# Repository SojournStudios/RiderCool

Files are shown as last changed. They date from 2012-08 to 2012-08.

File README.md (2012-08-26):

========
Overview and Description
========

>> RiderCool by Kristopher Kortright, June 2012 - Aug 2012 (o_o)
*>  This software is licensed via CERN Open Source Hardware License.
->  Must of this script was derived from tutorial code by Limor Fried 
->  and Adafruit Industries, and most of the credit goes to her and 
->  her company for providing such fantastic tutorials to the community!
->  Adafruit tutorials used can be found at http://learn.adafruit.com
->  My blog and projects can be found at http://sojournstudio.org/RiderCool

RiderCool has many purposes: 

1. Provide a technology platform for managing the pool with native XBee Network Protocol (XNP) support for sending data back for logging and to receive commands from a control router. 
2. To measure how full our pool is, and report that data back to my computer using my XBee Network Protocol (XNP) for logging and tracking (http://sojournstudio.org/xnp/)
3. To activate a solenoid/valve that is connected to a garden hose, which will fill the pool with water. 
4. To monitor, track and report-back the flow-rate of water going into the pool using an Adafruit flow-meter sensor (https://www.adafruit.com/products/828).
5. To monitor the temperature of the pool water, the ambient air, as well as ther CPU temp (https://www.adafruit.com/products/339), (https://www.adafruit.com/products/372)
6. To monitor a backup water-level sensor to ensure that the pool never over-flows.
7. To drive/control 4 RGB LED Strip controllers by Jeremy Saglimbeni; I have 40 meters of LED RGB Strip ringing-the pool. (http://thecustomgeek.com/2012/03/23/rgb ... r-ver-2-2/)
8. To displays the output of these sensors, LED status, etc on an Adafruit 1.8' TFT display for swimmers in the pool to see. (https://www.adafruit.com/products/358)
9. To provide button control resetting the system and controlling the RGB LED Strips using LED water-proof lights by Adafruit. (https://www.adafruit.com/products/482)
10. To teach me 3D printing - as this is my first 3D printing project with my MakerBot Replicator! (http://store.makerbot.com/replicator.html).
.
RiderCool was only possible because of the excellent products, tutorials and service that Limor Fried and her company Adafruit Industries provides to its customers, and I have become a dedicated fan over the 1.5 years I've been making. With this project I got to learn 3D printing and got some real use out of my years in Blender training. I also got to combine different products in a completely water-proof system. Now that it's done, of course, the summer is over and its nearly time to close the pool down. But building this helped me through alot of dark days this summer.
.
There are 4 modules (Otter Boxes) in the RiderCool system, each of which is documented below. I can only add 3 images to a post, so I'll reply to the post and add more content/images so I can show the creation pics as well as the final product when shown in action (Coming Soon!). The Power Module is a small-sized otter box with a laptop 12v/5A power supply and an adafruit 5V 2A power supply (https://www.adafruit.com/products/276) with the grounds tied-together.

The green power-button is actually not a power-button for the entire system, but rather a bypass power option that allows me to run the RGB LED Controllers by themselves without the Arduino Mega system controlling them (http://www.adafruit.com/products/916). 
.
The Interface Module combines an Adafruit 1.8' TFT display (http://www.adafruit.com/products/358) and several more water-proof buttons to allow users the ability to view the sensor stats and control the RGB LED strips while swimming in the pool.

Each of the 4 modules (otter boxes) are connected together using the new Adafruit waterproof power connectors (http://www.adafruit.com/products/743) and their new waterproof 4-wire connectors (http://www.adafruit.com/products/744). I love these things, and they came in very handy when the project grew beyond the size of one otter box! I plan to use them on most of my projects.

Lastly the RGB LED Controller module combines 4 of Jeremy's RGB LED controllers (http://thecustomgeek.com/2012/03/23/rgb ... r-ver-2-2/) in one large otter box, with the serial ports tied-together and fed into the Arduino for control. The switch allows me to use the strips manually (when combined with the green power button on the Power Module).

=========
Installation
=========
Simply install the RiderCoolNonXNP.pde script in your favorite arduino sketch directory, and load it as a project.
 
The sketch will compile cleanly on Arduino IDE v1.0.1 using the Arduino Mega 2560 as the board type.
 
You can follow-along with any changes I make here on GitHub, and make sure to check the Adafruit Forum post for RiderCool (http://forums.adafruit.com/viewtopic.php?f=25&t=32488) as that's where I will post lots of detail about the updates and answer any questions.
 
Cheers!
 
Kris Kortright

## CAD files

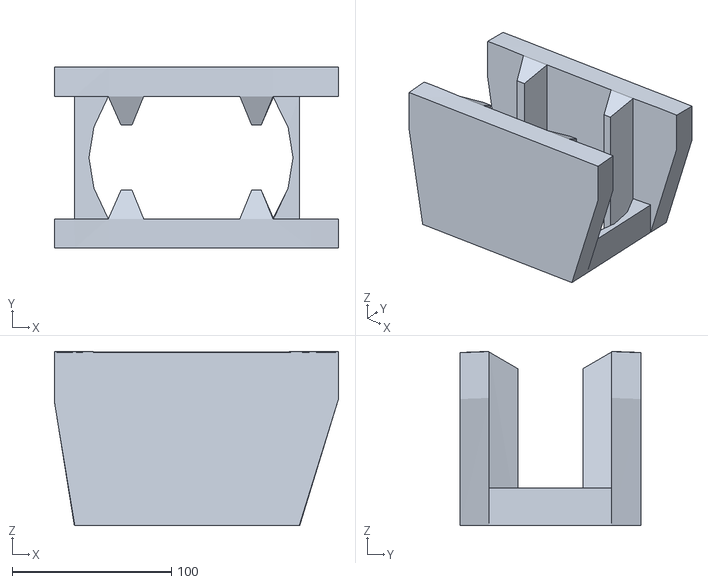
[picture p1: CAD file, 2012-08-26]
replicator/RiderCoolBacKMid4.stl
178.5 x 113.6 x 109.5

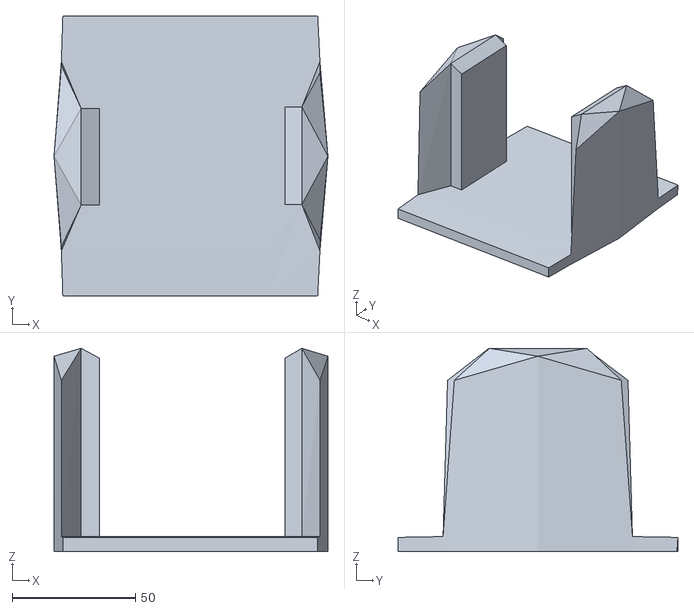
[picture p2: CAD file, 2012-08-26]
replicator/RiderCoolBackTop1.stl
111.2 x 113.6 x 82.5

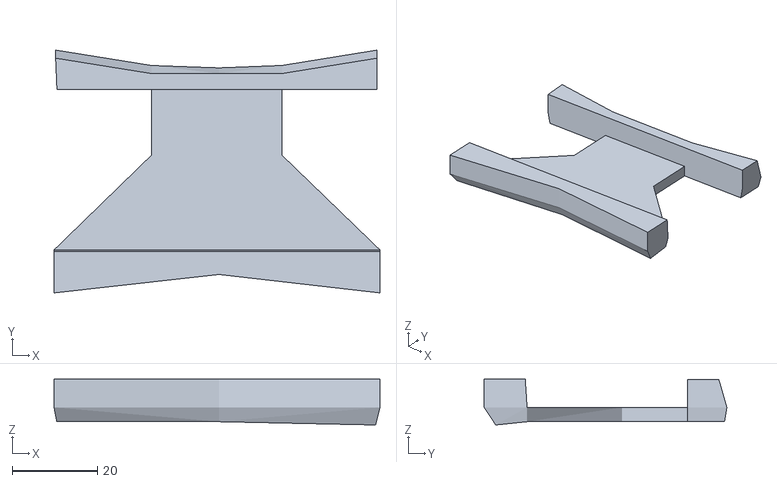
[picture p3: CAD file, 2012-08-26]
replicator/RiderCoolBackConnector1.stl
76.5 x 57.0 x 10.8

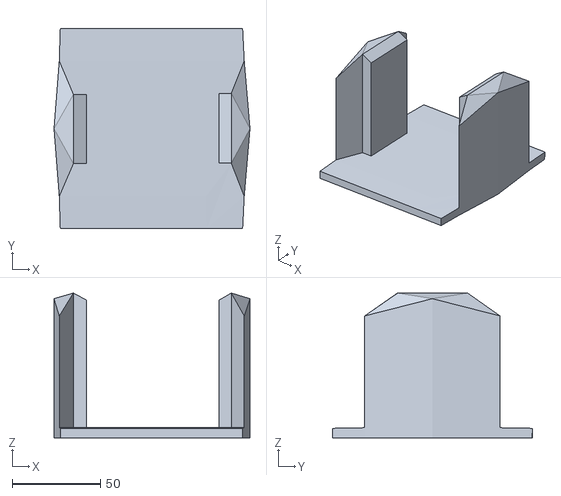
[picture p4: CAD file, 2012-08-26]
replicator/RiderCoolRearBaseTop1.stl
111.2 x 113.6 x 82.2

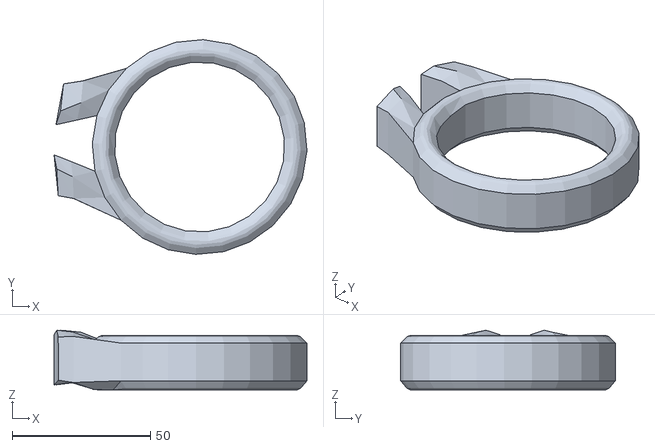
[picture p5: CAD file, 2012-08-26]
replicator/RiderCoolPoolRingMount.stl
91.6 x 77.7 x 21.6

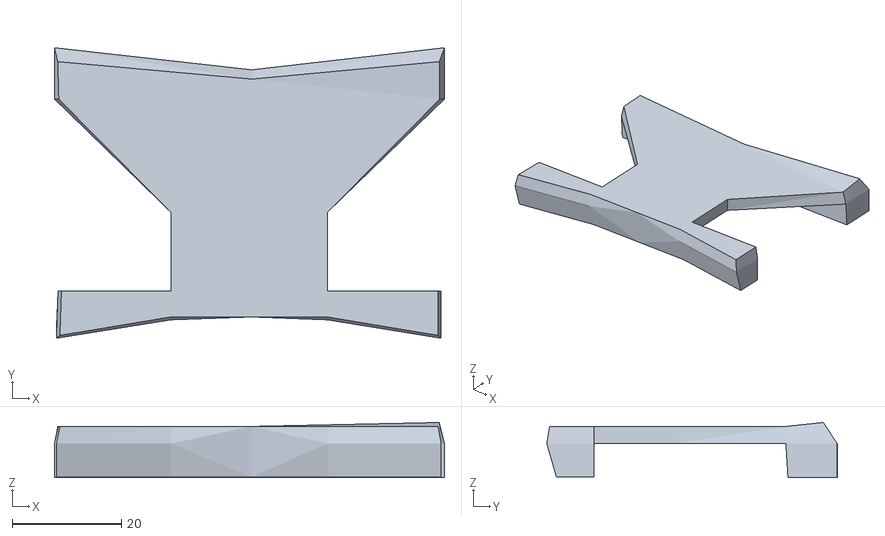
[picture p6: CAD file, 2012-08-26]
replicator/RiderCoolBaseLock1.stl
71.5 x 53.2 x 10.1

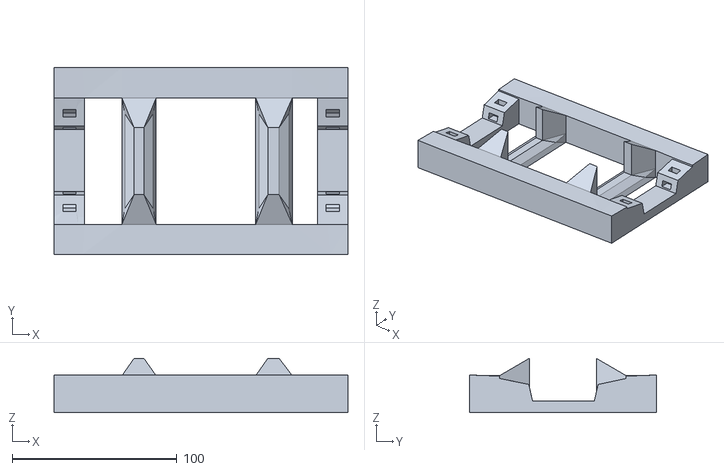
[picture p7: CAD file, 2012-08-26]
replicator/RiderCoolBackBase4.stl
178.5 x 113.6 x 33.0

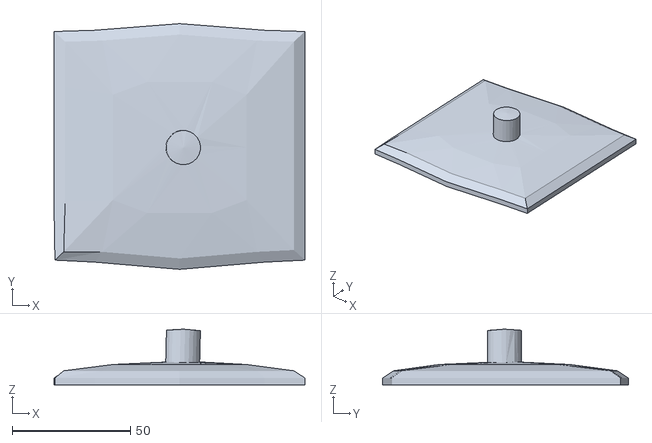
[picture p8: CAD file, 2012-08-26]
replicator/RiderCoolBackTopLid1.stl
106.1 x 103.9 x 23.6

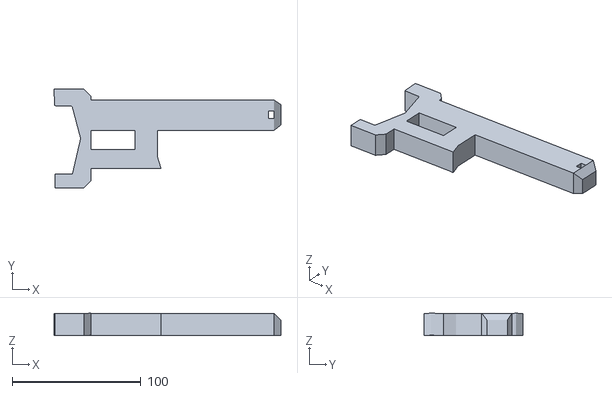
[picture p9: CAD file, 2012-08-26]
replicator/RiderCoolVertialRack4.stl
176.1 x 76.9 x 17.5

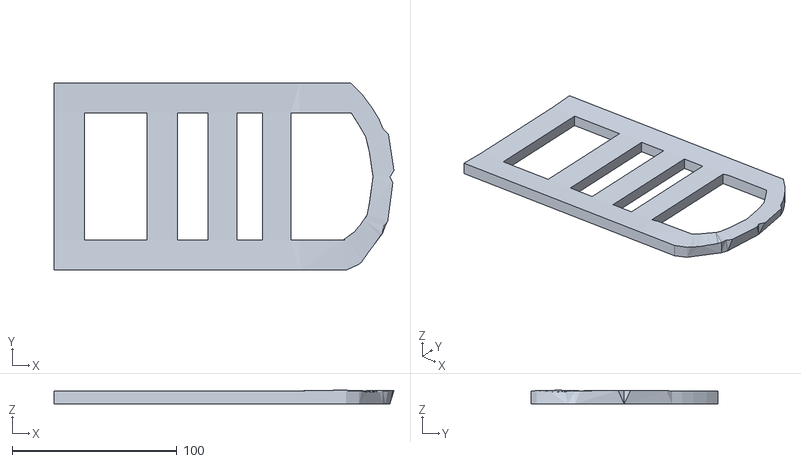
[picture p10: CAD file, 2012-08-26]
replicator/RiderCoolFrontBaseLowerWedge1.stl
206.1 x 113.6 x 8.39

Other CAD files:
blender/RiderCoolV1.blend

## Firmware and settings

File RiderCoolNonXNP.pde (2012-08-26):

/* =-=-=-=-=-=-=-=-=-=-=-=-=-=-=-=-=-=-=-=-=-=-=-=-=-=-=-=-=-=-=-=-=-=-=-=
RiderCool by Kristopher Kortright, June 2012 - Aug 2012 (o_o)
This software is licensed via CERN Open Source Hardware License
=-=-=-=-=-=-=-=-=-=-=-=-=-=-=-=-=-=-=-=-=-=-=-=-=-=-=-=-=-=-=-=-=-=-=-=-=*/
#define VERSION            "Ver 1.0"

#include <Wire.h>
#include <SPI.h>  // not used here, but needed to prevent a RTClib compile error
#include "RTClib.h"
RTC_Millis RTC;

#include <Adafruit_GFX.h>
#include <Adafruit_ST7735.h>
#include <SPI.h>
#include <Adafruit_BMP085.h>
Adafruit_BMP085 bmp;

int DigitalPSTdrivePIN1 = 36;
int DigitalPSTdrivePIN2 = 37; 
int DigitalPSTdrivePIN3 = 38;
int DigitalPSTdrivePIN4 = 39; 
int DigitalRELAYdrivePIN = 46;
int DigitalPINnetworkStateLEDred = 25;
int DigitalPINnetworkStateLEDblue = 27;
int DigitalPINnetworkStateLEDgreen = 29;
int DigitalPINcontrollerPower = 47;
int DigitalPINRGBLEDstatus = 49;
int DigitalPINxbeePacketInLED = 45;       
int DigitalPINxbeePacketOutLED = 44;
int DigitalPINxbeepacketLossLED = 43;
int AnalogPINrotaryA0 = 54;
int AnalogPINrotaryA1 = 55;
int AnalogPINrotaryA2 = 56;
int AnalogPINrotaryA3 = 57;
int AnalogPINtmp36tempA7 = 61;
int AnalogPINphotoCellA8 = 62;
int AnalogPINphotoCellA9 = 63;
int AnalogThermistorSensorPIN1 = 67;
int AnalogThermistorSensorPIN2 = 65;
int AnalogThermistorSensorPIN3 = 66;
int AnalogPINliquidLevelSensorA13 = 64;
int AnalogPINliquidLevelSensorA15 = 69;
int FlowSensorPIN = 58;
int AnalogPINbutton1 = 59;
int AnalogPINbutton2 = 60;
int TFT18shieldSCLKpin = 52;
int TFT18shieldMOSIpin = 51;
int DigitalTFT18shieldCsPIN = 53;
int DigitalTFT18shieldDcPIN = 9;
int DigitalTFT18shieldRstPIN = 8;
int DigitalTFT18shieldLightPIN  = 50;

#define MAX_BUFFER_LENGTH 192
int MAX_BUFFER_LENGTHS = 192;

int POWERSWITCH_ENABLE = 1;
int ButtonOneState = 1;
int ButtonTwoState = 1;
long e, f, g;
int a, b, c, d, h, j, k, r, s, t, x, y, z;
char buffer1[MAX_BUFFER_LENGTH], buffer2[MAX_BUFFER_LENGTH], buffer3[MAX_BUFFER_LENGTH], inChar;
int TempSensorCount = 3;
int MinutesNow, MinutesWas, HoursNow, SegmentCounter;
int MasterTEMPstatus = -1;
int AIRtempHIcount, CPUtempHIcount, COOLANTtempHIcount;
int TemperatureAIR, TemperatureCPU, TemperatureCOOLANT;
int TempHIwarnLevelAIR, TempHIalarmLevelAIR;
int TempHIwarnLevelCPU, TempHIalarmLevelCPU;
int TempHIwarnLevelCOOLANT, TempHIalarmLevelCOOLANT;
int AIRtempHIcountMAX, CPUtempHIcountMAX, COOLANTtempHIcountMAX;
float SensorAverageReading;
float steinhart;
float temperatureF;
int ThermistorTemp;
int SensorSamples[5];
int SensorSettleDelay;
long MasterSensor;
int FlexBaseline;
int LightLevel, FlexResistance, Tmp36temp;
int MAXIMUM_POOL_LEVEL = 200;
int MINIMUM_POOL_LEVEL = 240;
int FluidLevelAlarming = 0;
int poolButtonOneDelay = 0;
int poolButtonTwoDelay = 20;
int poolButtonOneCount, poolButtonTwoCount, WaterHoseValve;
int MiloneSensorReading, FloatSensorReading, FluidSensorReading, UnderFillAlarms;
int BMP085TempReading, BMP085PressureReading, BMP085AltitueReading;
int lastflowpinstate, FlowSensorReading, lastFlowSensorReadingtimer, pulses, flowpinstate;
int SensorModuleActive, SensorSamplePass, LightLevel2, PoolWaterLevelNum, PoolWaterLevelDem;
int BMPtemperatureRemain, BMPaltitudeRemain, varInBuf1, Remain1;
int BMPtemperature, BMPaltitude, SensorDisplayScreen, BMPsensorVectorNow;
int BMPpressureLastReading, BMPsensorCount, BMPsensorUpReadings, BMPsensorDownReadings, BMPpressureLastHour;
float fRemain1, fStart;
uint32_t BMPpressure, checkTime;

Adafruit_ST7735 tft = Adafruit_ST7735(DigitalTFT18shieldCsPIN, DigitalTFT18shieldDcPIN, DigitalTFT18shieldRstPIN);


// Sensor Constants - These were taken from example code by LadyAda (http://www.ladyada.net/learn/sensors/thermistor.html)
//  TMP36 Constants: (Touch these ONLY if you know what your doing, and even then I would be careful).
//  Tie the 3.3V bus to ARef so that the sensors are more accurate.
#define aref_voltage 3.3         
// Thermistor:
//   resistance at 25 degrees C
#define THERMISTORNOMINAL 10000      
//   temp. for nominal resistance (almost always 25 C)
#define TEMPERATURENOMINAL 25   
//   how many samples to take and SensorAverageReading, more takes longer
//   but is more 'smooth'
#define NUMSAMPLES 5
//   The beta coefficient of the thermistor (usually 3000-4000)
#define BCOEFFICIENT 3950
//   the value of the 'other' resistor
#define SERIESRESISTOR 10000    



void XNPlogger(const char *buffer4, int linefeed)
{
  if((linefeed == 0) || (linefeed == 1)) {   // If we want time-stamps on our log messages
    DateTime now = RTC.now();
    checkTime = now.unixtime();
    Serial.print("[");
    Serial.print(checkTime);
    Serial.print("] ");
  }
  if((linefeed == 1) || (linefeed == 3)) {
    Serial.print(buffer4);
  } else if((linefeed == 0) || (linefeed == 2)) {
    Serial.println(buffer4);
  }
}


void XNPcollectSensorData()
{
  if(SensorModuleActive == 1) {
    SensorSamplePass++;
    if(SensorSamplePass == 1) {
      SensorSamples[0] = analogRead(AnalogThermistorSensorPIN1);
    } else if(SensorSamplePass == 21) {
      SensorSamples[1] = analogRead(AnalogThermistorSensorPIN1);
    } else if(SensorSamplePass == 41) {
      SensorSamples[2] = analogRead(AnalogThermistorSensorPIN1);
    } else if(SensorSamplePass == 61) {
      SensorSamples[3] = analogRead(AnalogThermistorSensorPIN1);
    } else if(SensorSamplePass == 81) {
      SensorSamples[4] = analogRead(AnalogThermistorSensorPIN1);
      SensorAverageReading = 0;
      for(b = 0; b < 5; b++) {
         SensorAverageReading += SensorSamples[b];
      }
      SensorAverageReading /= 5;
      SensorAverageReading = 1023 / SensorAverageReading - 1;
      SensorAverageReading = SERIESRESISTOR / SensorAverageReading;
      steinhart = 0;
      steinhart = SensorAverageReading / THERMISTORNOMINAL;
      steinhart = log(steinhart);
      steinhart /= BCOEFFICIENT;
      steinhart += 1.0 / (TEMPERATURENOMINAL + 273.15);
      steinhart = 1.0 / steinhart;
      steinhart -= 273.15;   
      temperatureF = (steinhart * 9.0 / 5.0) + 32.0;
      TemperatureAIR = int(temperatureF);
      sprintf(buffer2, " ");
      XNPlogger(buffer2, 2);
      sprintf(buffer2, "-] Sensor Readings:");
      XNPlogger(buffer2, 2);
      sprintf(buffer2, "-] Thermistor #1 Temperature Reading: %d F, AlarmCount: %d", TemperatureAIR, AIRtempHIcount); 
      XNPlogger(buffer2, 2);  
    } else if(SensorSamplePass == 101) {
      SensorSamples[0] = analogRead(AnalogThermistorSensorPIN2);
    } else if(SensorSamplePass == 121) {
      SensorSamples[1] = analogRead(AnalogThermistorSensorPIN2);
    } else if(SensorSamplePass == 141) {
      SensorSamples[2] = analogRead(AnalogThermistorSensorPIN2);
    } else if(SensorSamplePass == 161) {
      SensorSamples[3] = analogRead(AnalogThermistorSensorPIN2);
    } else if(SensorSamplePass == 181) {
      SensorSamples[4] = analogRead(AnalogThermistorSensorPIN2);
      SensorAverageReading = 0;
      for(b = 0; b < 5; b++) {
         SensorAverageReading += SensorSamples[b];
      }
      SensorAverageReading /= 5;
      SensorAverageReading = 1023 / SensorAverageReading - 1;
      SensorAverageReading = SERIESRESISTOR / SensorAverageReading;
      steinhart = 0;
      steinhart = SensorAverageReading / THERMISTORNOMINAL;
      steinhart = log(steinhart);
      steinhart /= BCOEFFICIENT;
      steinhart += 1.0 / (TEMPERATURENOMINAL + 273.15);
      steinhart = 1.0 / steinhart;
      steinhart -= 273.15;   
      temperatureF = (steinhart * 9.0 / 5.0) + 32.0;
      TemperatureCPU = int(temperatureF);
      sprintf(buffer2, "-] Thermistor #2 Temperature Reading: %d F, AlarmCount: %d", TemperatureCPU, CPUtempHIcount); 
      XNPlogger(buffer2, 2);  
    } else if(SensorSamplePass == 201) {
      SensorSamples[0] = analogRead(AnalogThermistorSensorPIN3);
    } else if(SensorSamplePass == 221) {
      SensorSamples[1] = analogRead(AnalogThermistorSensorPIN3);
    } else if(SensorSamplePass == 241) {
      SensorSamples[2] = analogRead(AnalogThermistorSensorPIN3);
    } else if(SensorSamplePass == 261) {
      SensorSamples[3] = analogRead(AnalogThermistorSensorPIN3);
    } else if(SensorSamplePass == 281) {
      SensorSamples[4] = analogRead(AnalogThermistorSensorPIN3);
      SensorAverageReading = 0;
      for(b = 0; b < 5; b++) {
         SensorAverageReading += SensorSamples[b];
      }
      SensorAverageReading /= 5;
      SensorAverageReading = 1023 / SensorAverageReading - 1;
      SensorAverageReading = SERIESRESISTOR / SensorAverageReading;
      steinhart = 0;
      steinhart = SensorAverageReading / THERMISTORNOMINAL;
      steinhart = log(steinhart);
      steinhart /= BCOEFFICIENT;
      steinhart += 1.0 / (TEMPERATURENOMINAL + 273.15);
      steinhart = 1.0 / steinhart;
      steinhart -= 273.15;   
      temperatureF = (steinhart * 9.0 / 5.0) + 32.0;
      TemperatureCOOLANT = int(temperatureF);
      sprintf(buffer2, "-] Thermistor #3 Temperature Reading: %d F, AlarmCount: %d", TemperatureCOOLANT, COOLANTtempHIcount); 
      XNPlogger(buffer2, 2);
    } else if(SensorSamplePass == 301) {
      LightLevel = analogRead(AnalogPINphotoCellA8);
      LightLevel = map(LightLevel, 0, 900, 0, 10); 
      LightLevel = constrain(LightLevel, 0, 10);
      sprintf(buffer1, "-] Photo Cell Sensor #1 reading: %d)", LightLevel);
      XNPlogger(buffer1, 2);
    } else if(SensorSamplePass == 321) {
      LightLevel2 = analogRead(AnalogPINphotoCellA9);
      LightLevel2 = map(LightLevel2, 0, 900, 0, 10); 
      LightLevel2 = constrain(LightLevel2, 0, 10);
      sprintf(buffer1, "-] Photo Cell Sensor #2 reading: %d)", LightLevel2);
      XNPlogger(buffer1, 2);
    } else if(SensorSamplePass == 341) {
      SensorSamples[0] = analogRead(AnalogPINliquidLevelSensorA13);
    } else if(SensorSamplePass == 361) {
      SensorSamples[1] = analogRead(AnalogPINliquidLevelSensorA13);
    } else if(SensorSamplePass == 381) {
      SensorSamples[2] = analogRead(AnalogPINliquidLevelSensorA13);
    } else if(SensorSamplePass == 401) {
      SensorSamples[3] = analogRead(AnalogPINliquidLevelSensorA13);
    } else if(SensorSamplePass == 421) {
      SensorSamples[4] = analogRead(AnalogPINliquidLevelSensorA13);
      SensorAverageReading = 0;
      for(b = 0; b < 5; b++) {
         SensorAverageReading += SensorSamples[b];
      }
      SensorAverageReading /= 5;
      FloatSensorReading = SensorAverageReading;
      sprintf(buffer2, "-] Liquid Float Sensor: %d", FloatSensorReading); 
      XNPlogger(buffer2, 2);
    } else if(SensorSamplePass == 441) {
      SensorSamples[0] = analogRead(AnalogPINliquidLevelSensorA15);
    } else if(SensorSamplePass == 461) {
      SensorSamples[1] = analogRead(AnalogPINliquidLevelSensorA15);
    } else if(SensorSamplePass == 481) {
      SensorSamples[2] = analogRead(AnalogPINliquidLevelSensorA15);
    } else if(SensorSamplePass == 501) {
      SensorSamples[3] = analogRead(AnalogPINliquidLevelSensorA15);
    } else if(SensorSamplePass == 521) {
      SensorSamples[4] = analogRead(AnalogPINliquidLevelSensorA15);
      SensorAverageReading = 0;
      for(b = 0; b < 5; b++) {
         SensorAverageReading += SensorSamples[b];
      }
      SensorAverageReading /= 5;
      MiloneSensorReading = SensorAverageReading;
      sprintf(buffer2, "-] Liquid Milone Sensor: %d", MiloneSensorReading); 
      XNPlogger(buffer2, 2);
    } else if((SensorSamplePass > 540) && (SensorSamplePass < 562)) {
      digitalWrite(FlowSensorPIN, HIGH);
      flowpinstate = digitalRead(FlowSensorPIN);
      if(flowpinstate == lastflowpinstate) {
        lastFlowSensorReadingtimer++;
      } else {
        if(flowpinstate == HIGH) {
          //low to high transition!
          pulses++;
        }
        lastflowpinstate = flowpinstate;
        FlowSensorReading = 1000.0;
        FlowSensorReading /= lastFlowSensorReadingtimer;  // in hertz
        lastFlowSensorReadingtimer = 0;
        sprintf(buffer2, "-] Flow Sensor: %d", FlowSensorReading); 
        XNPlogger(buffer2, 2);
      }
    } else if(SensorSamplePass == 600) {
      fStart = bmp.readTemperature();
      if(fStart < 1) {
        varInBuf1 = 0;
        Remain1 = 0;
      } else {
        varInBuf1 = int(fStart);
        fRemain1 = fStart - varInBuf1;
        fRemain1 = fRemain1 * 100;
        Remain1 = int(fRemain1);
      }
      BMPtemperature = int(varInBuf1);
      BMPtemperatureRemain = Remain1;
      fStart = bmp.readAltitude(101500);
      if(fStart < 1) {
        varInBuf1 = 0;
        Remain1 = 0;
      } else {
        varInBuf1 = int(fStart);
        fRemain1 = fStart - varInBuf1;
        fRemain1 = fRemain1 * 100;
        Remain1 = int(fRemain1);
      }
      BMPaltitude = int(varInBuf1);
      BMPaltitudeRemain = Remain1;
      BMPpressureLastReading = BMPpressure;
      BMPpressure = bmp.readPressure();
      if(BMPpressure > BMPpressureLastReading) {
        BMPsensorDownReadings++;
        BMPsensorVectorNow = 2;
      } else {
        BMPsensorUpReadings++;
        BMPsensorVectorNow = 1;
      }
      DateTime now = RTC.now();
      MinutesNow = now.minute();
      if(MinutesNow == 0) {
        if(BMPsensorCount == 0) {
          BMPsensorCount = 1;
          if(BMPsensorUpReadings > BMPsensorDownReadings) {
            BMPpressureLastHour = 2;
          } else {
            BMPpressureLastHour = 1;
          }
          BMPsensorUpReadings = 0;
          BMPsensorDownReadings = 0;
        }
      } else if(MinutesNow == 1) {
        BMPsensorCount = 0;
      }
      sprintf(buffer2, "-] Current BMP Temp: %d.%d, Pressure: %lu (%lu), Altitude: %d.%d", 
        BMPtemperature, BMPtemperatureRemain, BMPpressure, BMPpressureLastReading, BMPaltitude, BMPaltitudeRemain); 
      XNPlogger(buffer2, 2);
      sprintf(buffer2, "-] Pressure Up Readings: %d, Pressure Down Readings: %d, Vector Now: %d, Vector Last Hour: %d", 
        BMPsensorUpReadings, BMPsensorDownReadings, BMPpressureLastHour, BMPsensorVectorNow);
      XNPlogger(buffer2, 2);
      SensorSamplePass == 0;
      SensorModuleActive = 2;
    }
  }
}
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
void loop()
{
  MasterSensor++;

  // Process all sensor readings.
  if(MasterSensor > 150000) {
    MasterSensor = 0;
    SensorModuleActive = 1;
  }
  if(SensorModuleActive == 1) {
    XNPcollectSensorData();
  }
  if(SensorModuleActive == 2) {
    XNPprocessPoolControlSensorData();
    XNPdisplayPoolControlSensorData();
  }

  // Handle the two option buttons elegantly (for the user)
  if(poolButtonOneDelay < 1) {
    g = analogRead(AnalogPINbutton1);
    if(g < 100) {
      poolButtonOneCount++;
    } else {
      poolButtonOneCount = 0;
      ButtonOneState = 0;
    }
    poolButtonOneDelay = 40;
  } else {
    poolButtonOneDelay--;
  }
  if(poolButtonTwoDelay < 1) {
    g = analogRead(AnalogPINbutton2);
    if(g > 100) {
      poolButtonTwoCount++;
    } else {
      poolButtonTwoCount = 0;
      ButtonTwoState = 0;
    }
    poolButtonTwoDelay = 40;
  } else {
    poolButtonTwoDelay--;
  }
  if(poolButtonOneCount == 50) {
    ButtonOneState = 1;
    poolButtonOneCount = 0;
  }
  if(poolButtonTwoCount == 50) {
    ButtonTwoState = 1;
    poolButtonTwoCount = 0;
  }
  if((ButtonOneState == 1) && (ButtonTwoState == 1)) {
    sprintf(buffer1, "BUTTONS #1 and #2 HIT!");
    XNPlogger(buffer1, 0);
    ButtonOneState = 2;
    ButtonTwoState = 2;
    poolButtonOneDelay = 2000;
    poolButtonTwoDelay = 2000;
    // Do something
  } else if((ButtonOneState == 1) && (ButtonTwoState == 0)) {
    sprintf(buffer1, "BUTTON #1 HIT!");
    XNPlogger(buffer1, 0);
    g = 0;
    ButtonOneState = 2;
    poolButtonOneDelay = 2000;
    sprintf(buffer1, "stop");
    Serial3.print(buffer1); 
    // Do something
  } else if((ButtonOneState == 0) && (ButtonTwoState == 1)) {
    sprintf(buffer1, "BUTTON #2 HIT!");
    XNPlogger(buffer1, 0);
    h = 1023;
    ButtonTwoState = 2;
    poolButtonTwoDelay = 2000;
    sprintf(buffer1, "cycle");
    Serial3.print(buffer1); 
    // Do something
  }
}
